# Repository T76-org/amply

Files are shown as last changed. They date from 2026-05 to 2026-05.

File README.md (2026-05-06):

# Amply - a $10 Bluetooth amplifier you'll love

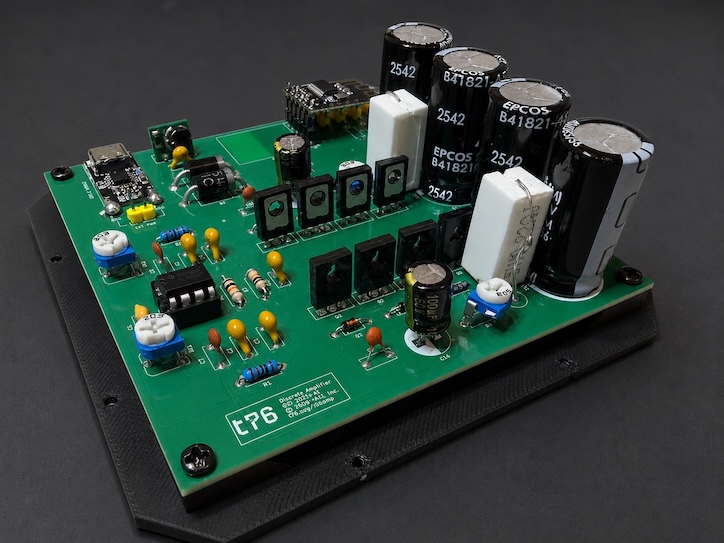
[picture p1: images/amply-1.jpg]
Amply Bluetooth amplifier


**Amply** is a compact, high-quality audio amplifier and Bluetooth receiver that can be built from roughly $10 worth of widely available parts.

Designed for desktop speakers, it delivers up to 2×10 W into 8 Ω loads while running from an ordinary USB-C power adapter. The entire design uses common, easy-to-source components, making it practical to build almost anywhere.

Despite its low cost, Amply offers surprisingly strong audio performance: THD below 0.015%, excellent linearity, and a flat response extending down to 20 Hz for deep bass, clean mids, and detailed highs.

- [Interactive BOM](./bom/ibom.html)
- [Interactive schematic](https://kicanvas.org/?repo=https%3A%2F%2Fgithub.com%2FT76-org%2Famply)
- [Production files](./production)
- [Reference 3D enclosure](./enclosure)

## Features

- 2-channel Bluetooth 5.0 audio receiver
    - Optional On/Off, muting, pause, next/previous track controls
- Class AB amplifier capable of delivering up to 2×10 W into 8 Ω
- THD (simulated) below 0.015% at 10W
- Largely-flat frequency response from 20 Hz to 20 kHz
- Powered by a standard USB-C power adapter (5-20 V, 1 A)

## Physical design

- Compact PCB design (100 mm × 100 mm)
- Fully open-source
- Easy to assemble; requires only basic soldering skills and a few common tools
- Uses widely available, low-cost components (total cost around $10)
- 3D-printed enclosure design included in the repository

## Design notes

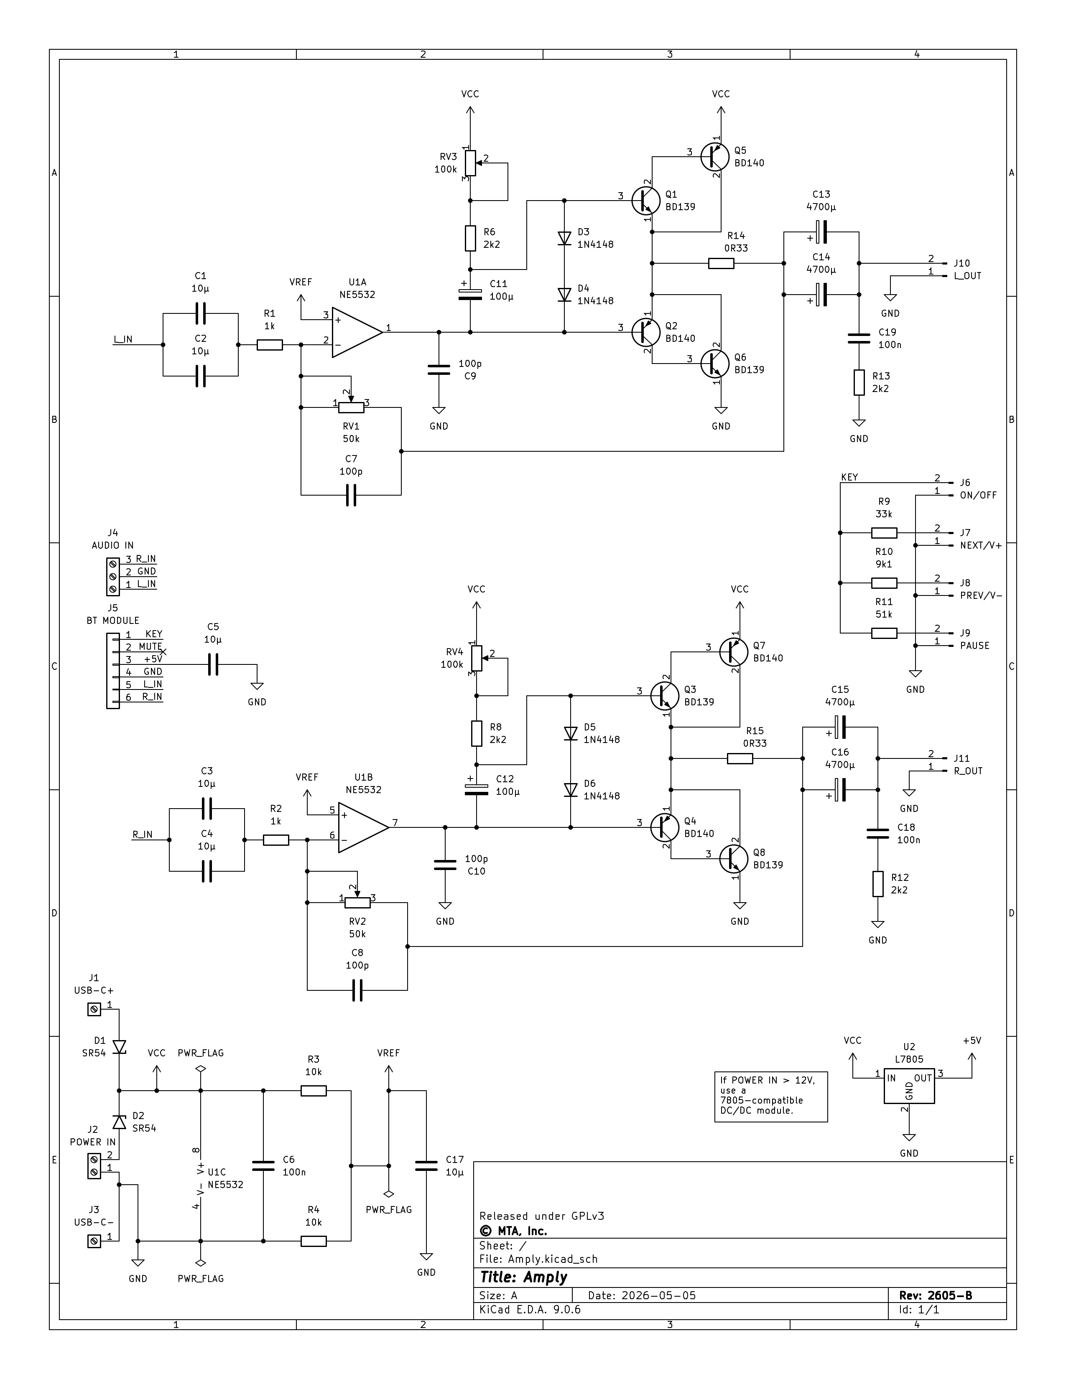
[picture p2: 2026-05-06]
images/amply-schematic-2605-B.jpg

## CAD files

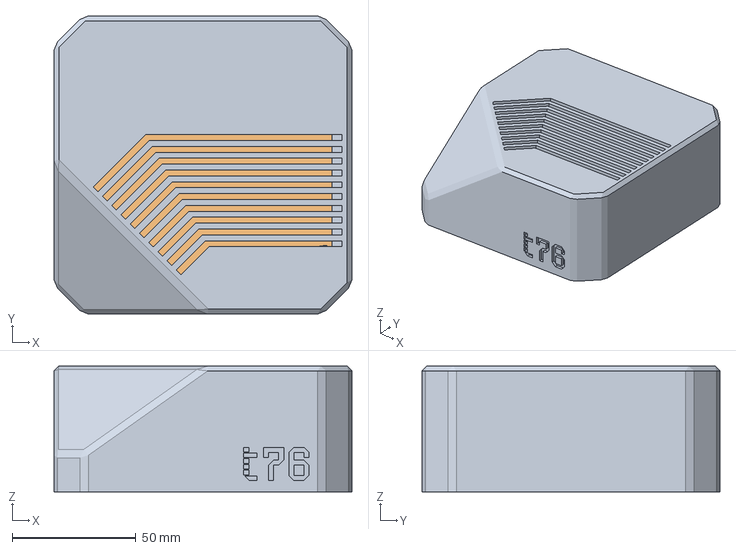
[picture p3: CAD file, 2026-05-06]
enclosure/Amply enclosure v4.3mf
120.2 x 120.2 x 50.8 mm

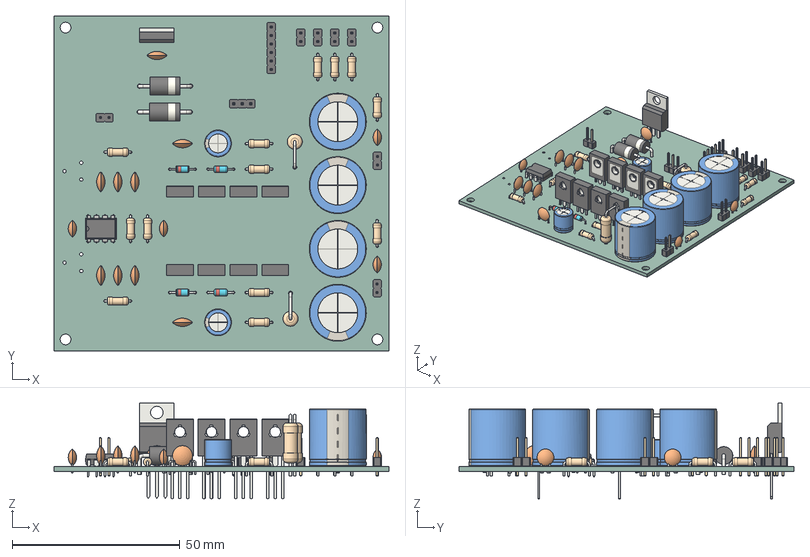
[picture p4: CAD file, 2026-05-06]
models/Amply.step
100.0 x 100.0 x 28.5 mm
CP_Radial_D17.0mm_P7.50mm x 4
D_DO-35_SOD27_P7.62mm_Horizontal x 4
PinHeader_1x02_P2.54mm_Vertical x 7
PinHeader_1x03_P2.54mm_Vertical
TO-220-3_Vertical
C_Disc_D6.0mm_W2.5mm_P5.00mm x 9
TO-126-3_Vertical x 8
R_Axial_DIN0207_L6.3mm_D2.5mm_P7.62mm_Horizontal x 13
C_Disc_D5.0mm_W2.5mm_P2.50mm x 4
DIP-8_W7.62mm
D_DO-201AE_P15.24mm_Horizontal x 2
CP_Radial_D8.0mm_P3.80mm x 2
R_Axial_DIN0414_L11.9mm_D4.5mm_P7.62mm_Vertical x 2
PinHeader_1x06_P2.54mm_Vertical
Discrete Amplifier_PCB

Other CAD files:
enclosure/Amply enclosure v4.stl

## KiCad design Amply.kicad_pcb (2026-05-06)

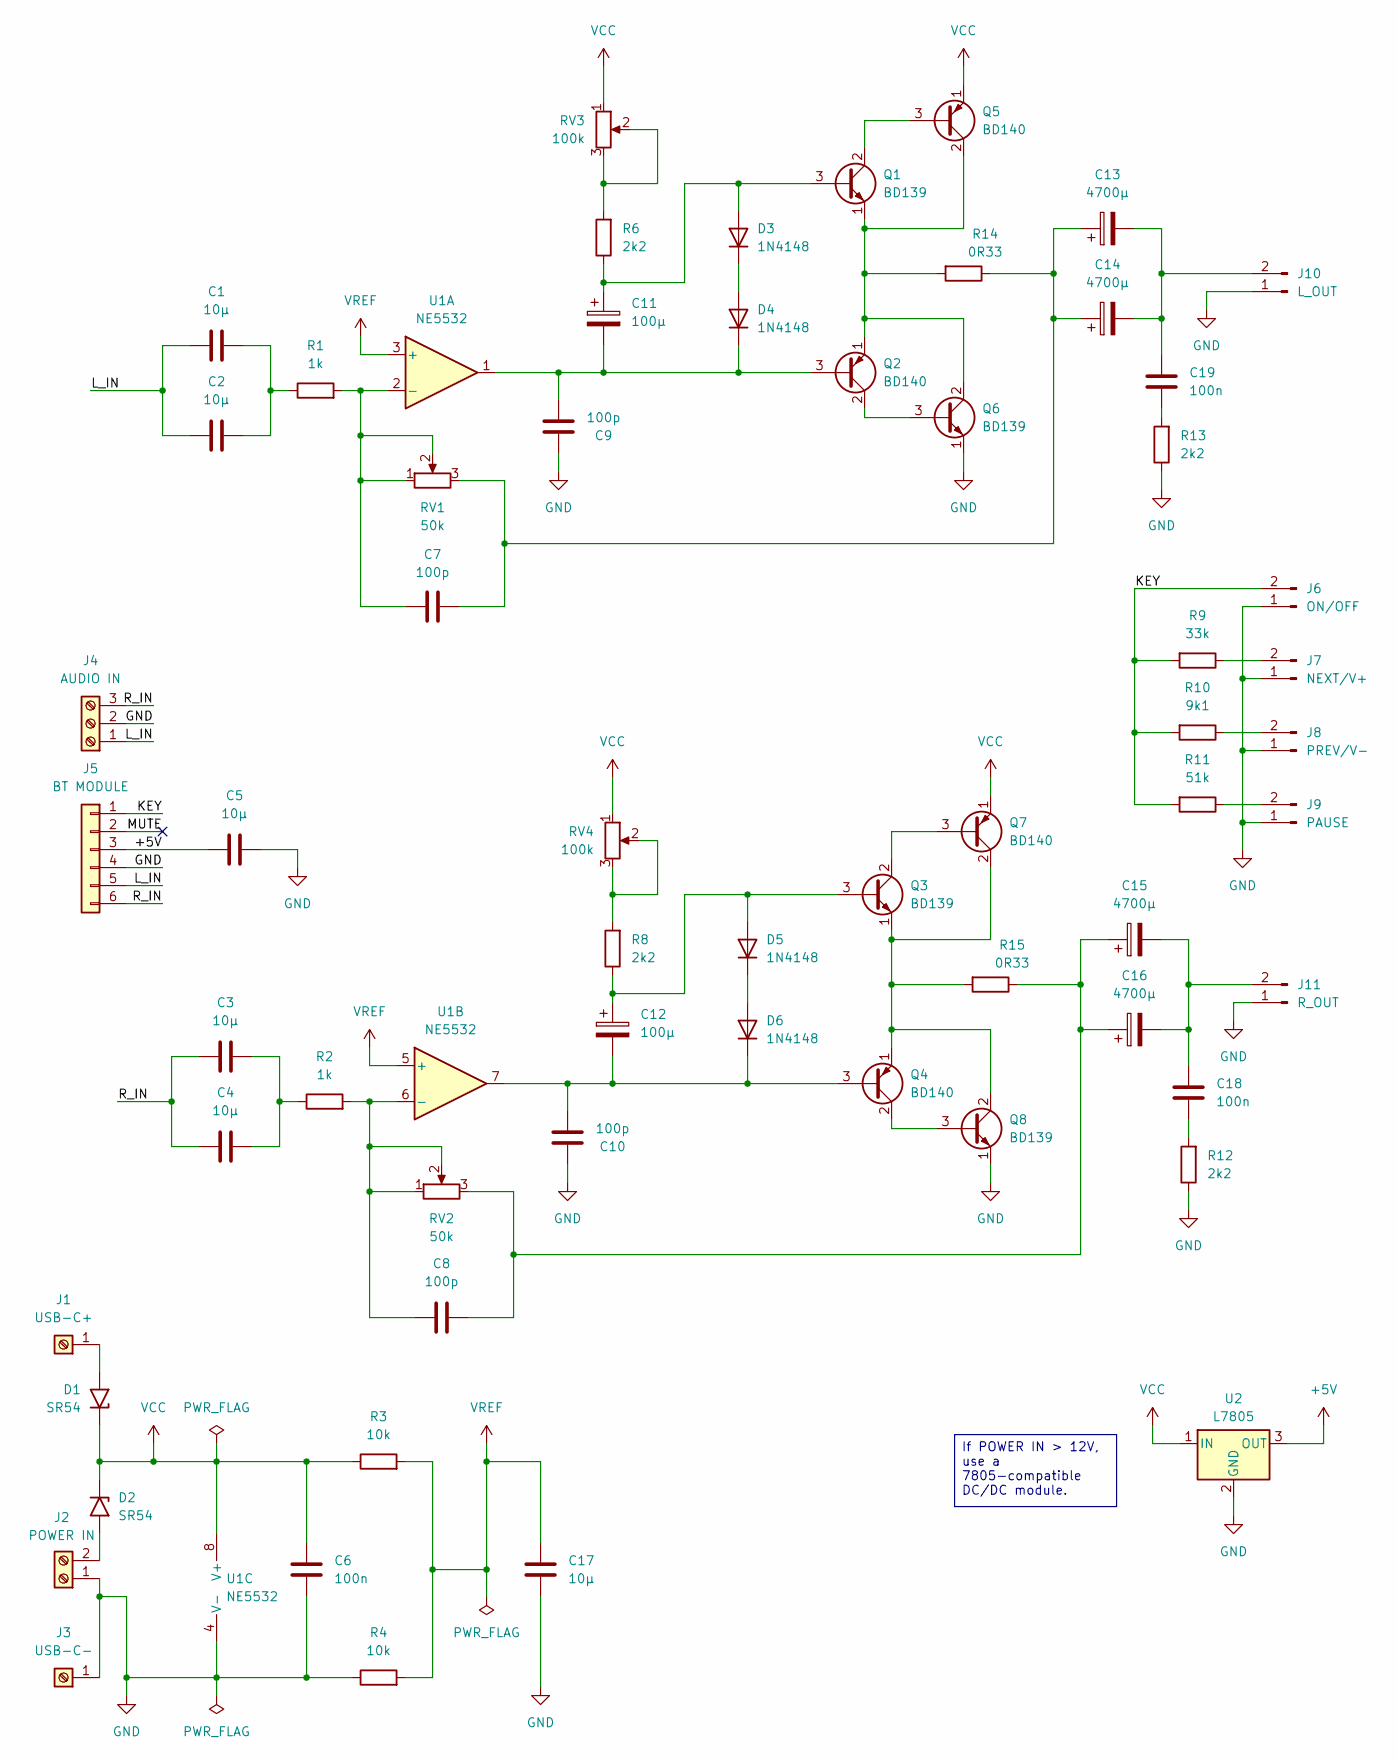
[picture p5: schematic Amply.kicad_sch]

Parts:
C1, C2, C3, C4, C5: 10µ; C_Disc_D6.0mm_W2.5mm_P5.00mm
C6, C18, C19: 100n; C_Disc_D5.0mm_W2.5mm_P2.50mm
C7, C8, C9, C10: 100p; C_Disc_D6.0mm_W2.5mm_P5.00mm
C11, C12: 100µ; CP_Radial_D8.0mm_P3.80mm
C13, C14, C15, C16: 4700µ; CP_Radial_D17.0mm_P7.50mm
C17: 10µ; C_Disc_D5.0mm_W2.5mm_P2.50mm
D1, D2: SR54; D_DO-201AE_P15.24mm_Horizontal
D3, D4, D5, D6: 1N4148; D_DO-35_SOD27_P7.62mm_Horizontal
J1: USB-C+; SolderWirePad_1x01_SMD_2x4mm
J2: POWER IN; PinHeader_1x02_P2.54mm_Vertical
J3: USB-C-; SolderWirePad_1x01_SMD_2x4mm
J4: AUDIO IN; PinHeader_1x03_P2.54mm_Vertical
J5: BT MODULE; PinHeader_1x06_P2.54mm_Vertical
J6: ON/OFF; PinHeader_1x02_P2.54mm_Vertical
J7: NEXT/V+; PinHeader_1x02_P2.54mm_Vertical
J8: PREV/V-; PinHeader_1x02_P2.54mm_Vertical
J9: PAUSE; PinHeader_1x02_P2.54mm_Vertical
J10: L_OUT; PinHeader_1x02_P2.54mm_Vertical
J11: R_OUT; PinHeader_1x02_P2.54mm_Vertical
Q1, Q3, Q6, Q8: BD139; TO-126-3_Vertical
Q2, Q4, Q5, Q7: BD140; TO-126-3_Vertical
R1, R2: 1k; R_Axial_DIN0207_L6.3mm_D2.5mm_P7.62mm_Horizontal
R3, R4: 10k; R_Axial_DIN0207_L6.3mm_D2.5mm_P7.62mm_Horizontal
R6, R8, R12, R13: 2k2; R_Axial_DIN0207_L6.3mm_D2.5mm_P7.62mm_Horizontal
R9: 33k; R_Axial_DIN0207_L6.3mm_D2.5mm_P7.62mm_Horizontal
R10: 9k1; R_Axial_DIN0207_L6.3mm_D2.5mm_P7.62mm_Horizontal
R11: 51k; R_Axial_DIN0207_L6.3mm_D2.5mm_P7.62mm_Horizontal
R14, R15: 0R33; R_Axial_DIN0414_L11.9mm_D4.5mm_P7.62mm_Vertical
RV1, RV2: 50k; Potentiometer_Runtron_RM-065_Vertical
RV3, RV4: 100k; Potentiometer_Runtron_RM-065_Vertical
U1: NE5532; DIP-8_W7.62mm_LongPads
U2: L7805; TO-220-3_Vertical

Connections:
+5V: C5.1, J5.3, U2.3 (OUT)
/KEY: J5.1, J6.2, R9.2, R10.2, R11.2
/L_IN: C1.1, C2.1, J4.1, J5.5
/MUTE: J5.2
/R_IN: C3.1, C4.1, J4.3, J5.6
GND: C5.2, C6.2, C9.1, C10.1, C17.2, J2.1, J3.1, J4.2, J5.4, J6.1, J7.1, J8.1, J9.1, J10.1, J11.1, Q6.1 (E), Q8.1 (E), R4.1, R12.1, R13.1, U1.4 (V-), U2.2 (GND)
unnamed: C1.2, C2.2, R1.1
unnamed: C3.2, C4.2, R2.1
unnamed: C7.2, C13.1, C14.1, R14.1, RV1.3
unnamed: C8.2, C15.1, C16.1, R15.1, RV2.3
unnamed: C18.2, R12.2
unnamed: C19.2, R13.2
unnamed: D1.2 (A2), J1.1
unnamed: D2.2 (A2), J2.2
unnamed: C11.1, D3.2 (A), Q1.3 (B), R6.1
unnamed: D3.1 (K), D4.2 (A)
unnamed: C9.2, C11.2, D4.1 (K), Q2.3 (B), U1.1
unnamed: C12.1, D5.2 (A), Q3.3 (B), R8.1
unnamed: D5.1 (K), D6.2 (A)
unnamed: C10.2, C12.2, D6.1 (K), Q4.3 (B), U1.7
unnamed: J7.2, R9.1
unnamed: J8.2, R10.1
unnamed: J9.2, R11.1
unnamed: C13.2, C14.2, C19.1, J10.2
unnamed: C15.2, C16.2, C18.1, J11.2
unnamed: Q1.2 (C), Q5.3 (B)
unnamed: Q1.1 (E), Q2.1 (E), Q5.2 (C), Q6.2 (C), R14.2
unnamed: Q2.2 (C), Q6.3 (B)
unnamed: Q3.2 (C), Q7.3 (B)
unnamed: Q3.1 (E), Q4.1 (E), Q7.2 (C), Q8.2 (C), R15.2
unnamed: Q4.2 (C), Q8.3 (B)
unnamed: R6.2, RV3.2, RV3.3
unnamed: R8.2, RV4.2, RV4.3
unnamed: C7.1, R1.2, RV1.1, RV1.2, U1.2 (-)
unnamed: C8.1, R2.2, RV2.1, RV2.2, U1.6 (-)
VCC: C6.1, D1.1 (A1), D2.1 (A1), Q5.1 (E), Q7.1 (E), R3.1, RV3.1, RV4.1, U1.8 (V+), U2.1 (IN)
VREF: C17.1, R3.2, R4.2, U1.3 (+), U1.5 (+)

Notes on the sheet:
If POWER IN > 12V, use a 7805-compatible DC/DC module.

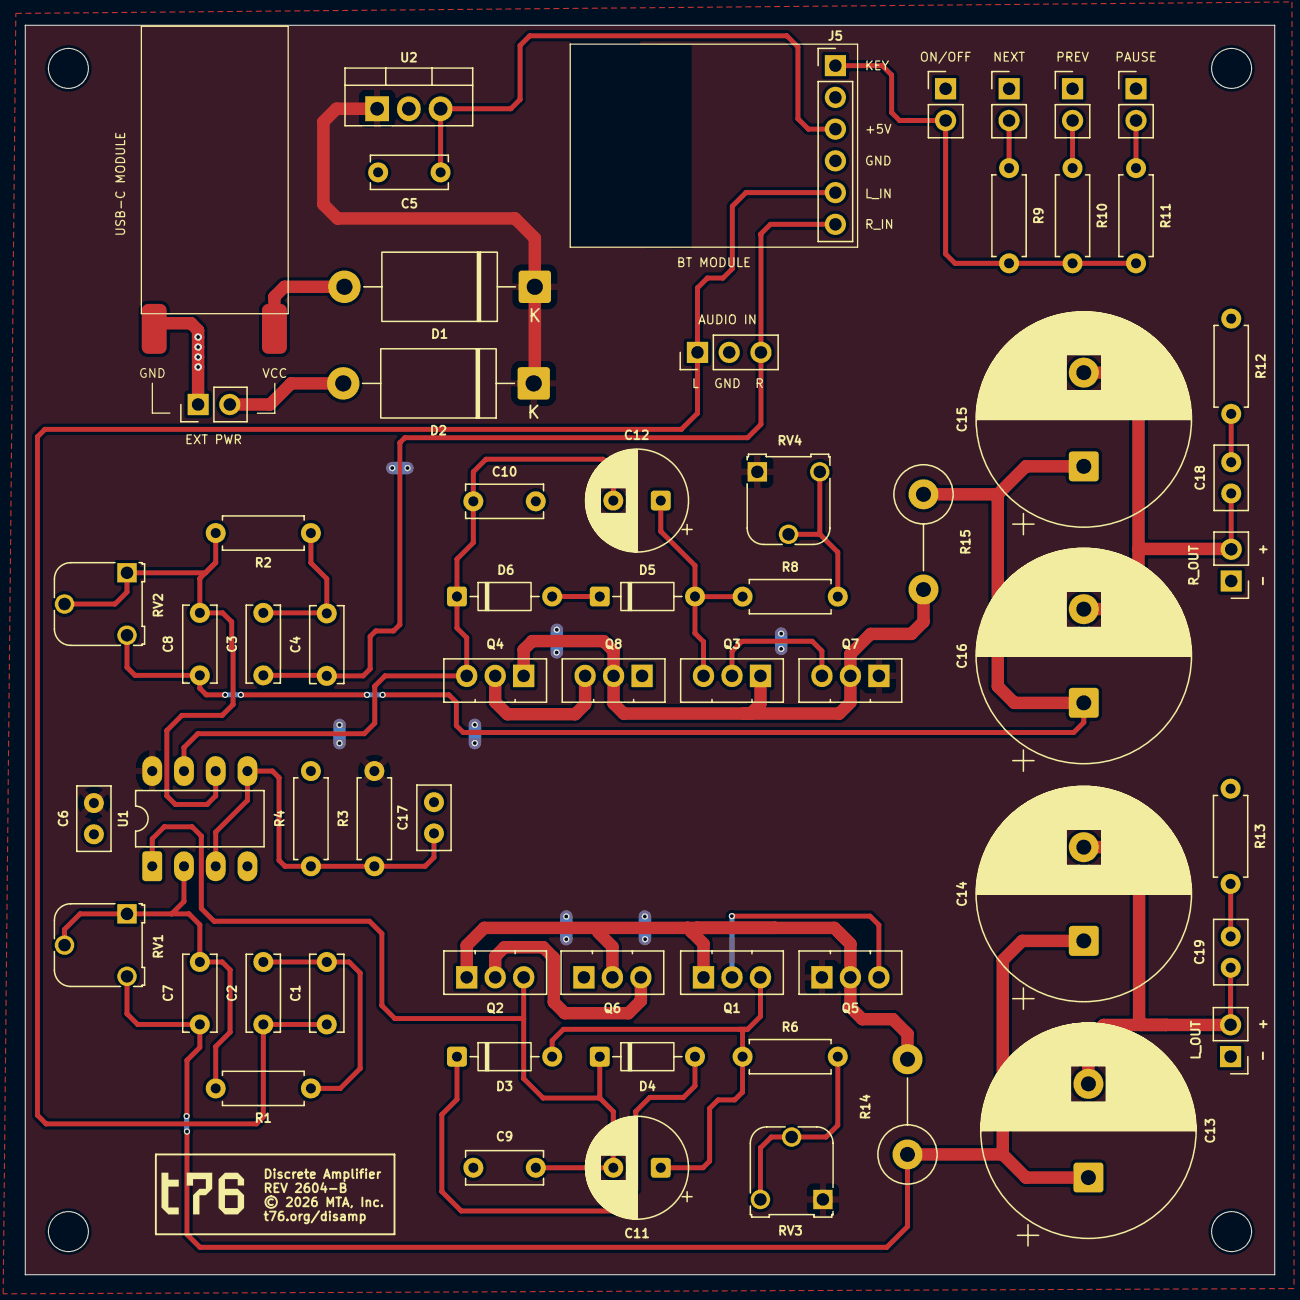
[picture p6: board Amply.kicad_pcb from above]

Board: 2 copper layers, 100.0 x 100.0 mm, 63 parts (0 on the bottom side), 36 nets.

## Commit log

2026-05-06 - Enclosure - Gerbers - Update README
    [Amply enclosure v4.3mf, Amply enclosure v4.stl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]
2026-05-06 Update README.md with production files and reference enclosure; remove obsolete fabrication toolkit and production files

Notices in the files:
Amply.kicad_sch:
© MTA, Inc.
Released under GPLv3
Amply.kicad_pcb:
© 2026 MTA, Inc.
